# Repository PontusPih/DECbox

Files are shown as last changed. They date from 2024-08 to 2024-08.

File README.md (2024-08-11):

# DECbox
Blueprints and requirements for a box used to store DEC flipchips

## Examples

Overall dimensions for single, dual and quad cards:
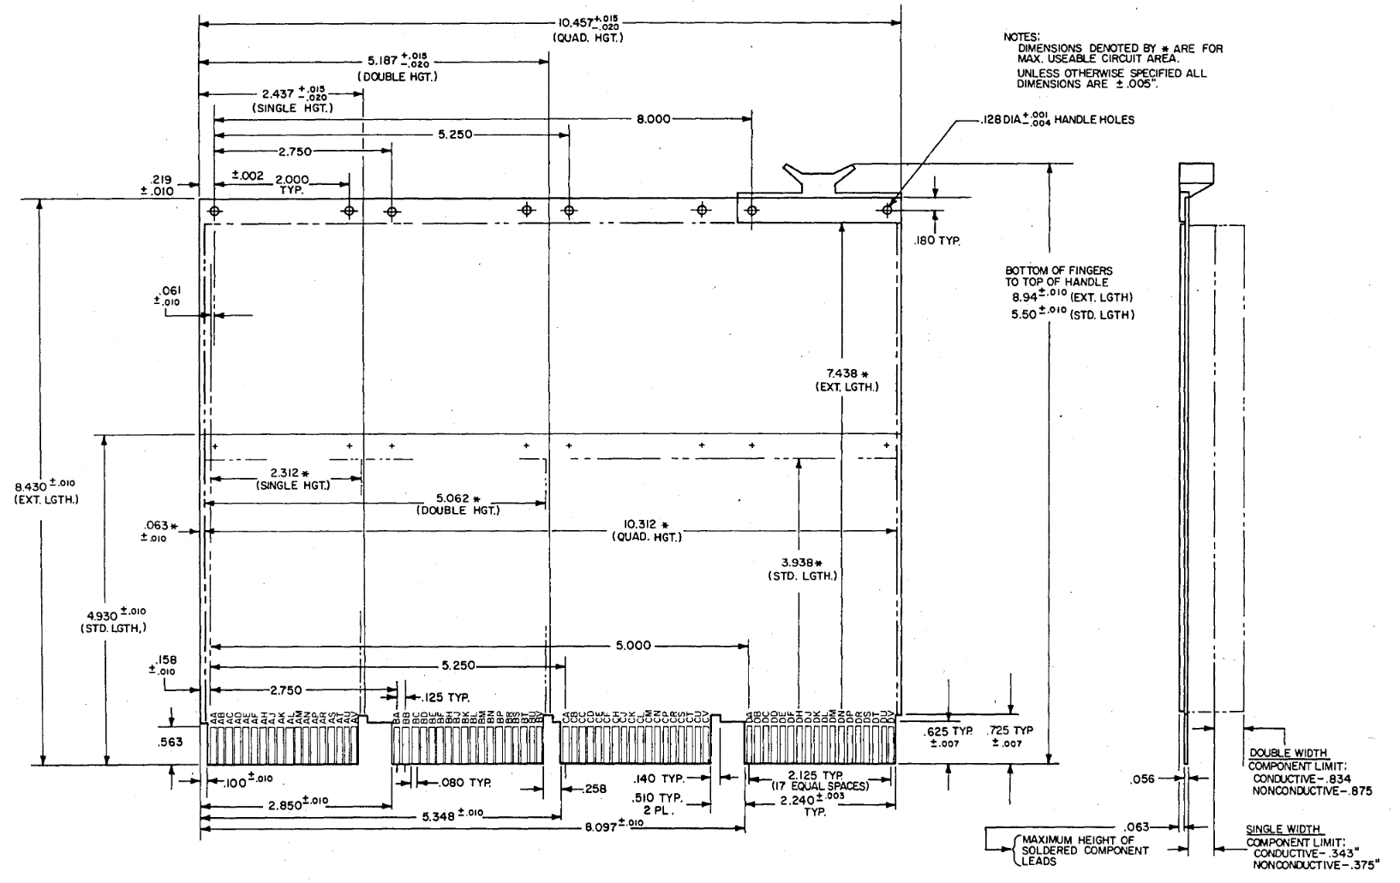
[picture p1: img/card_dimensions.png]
Card dimension


Overall dimesions for example Hex card (DH-11)

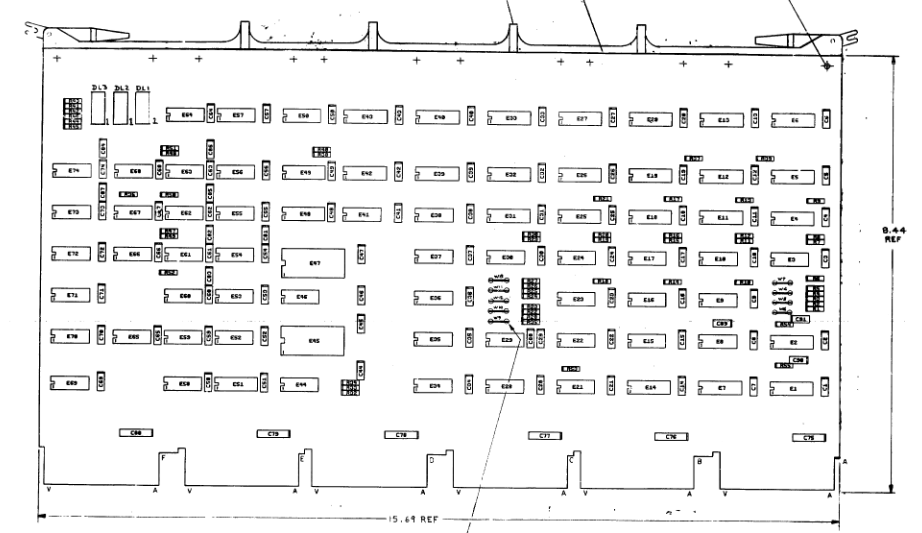
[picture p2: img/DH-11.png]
DH-11 drawing


Perspective views:

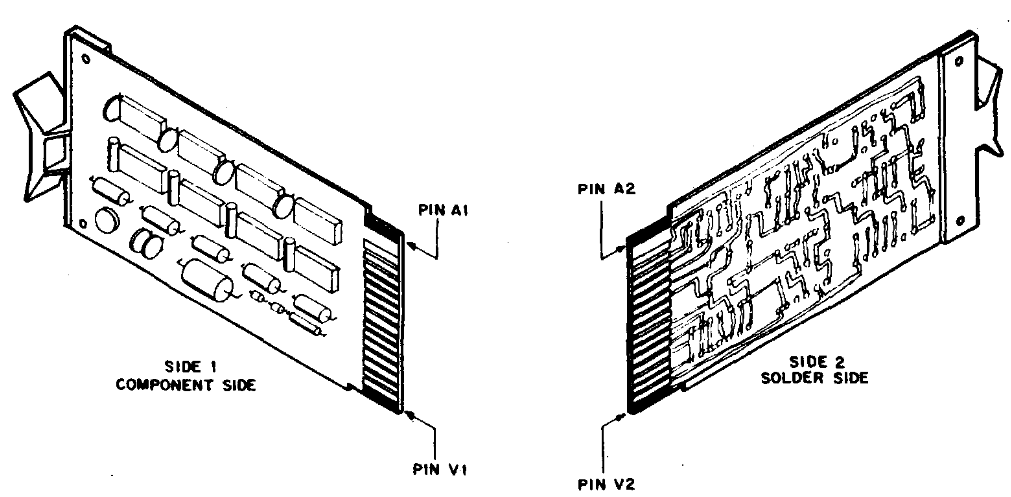
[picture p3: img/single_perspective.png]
Single card perspective


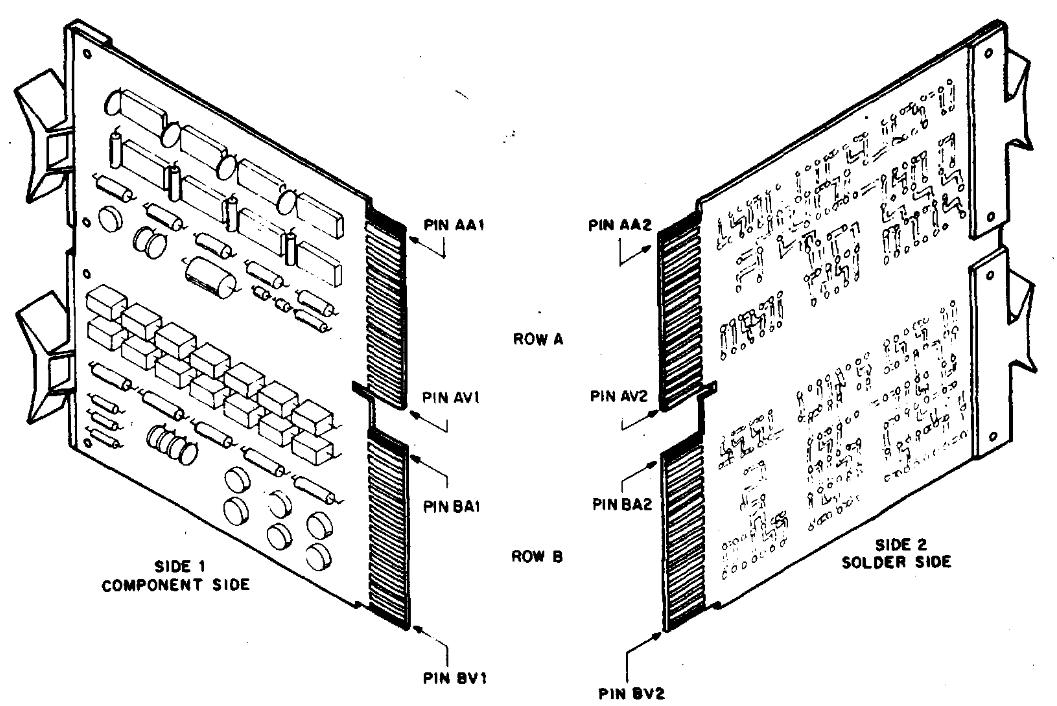
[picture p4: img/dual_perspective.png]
Dual card perspective


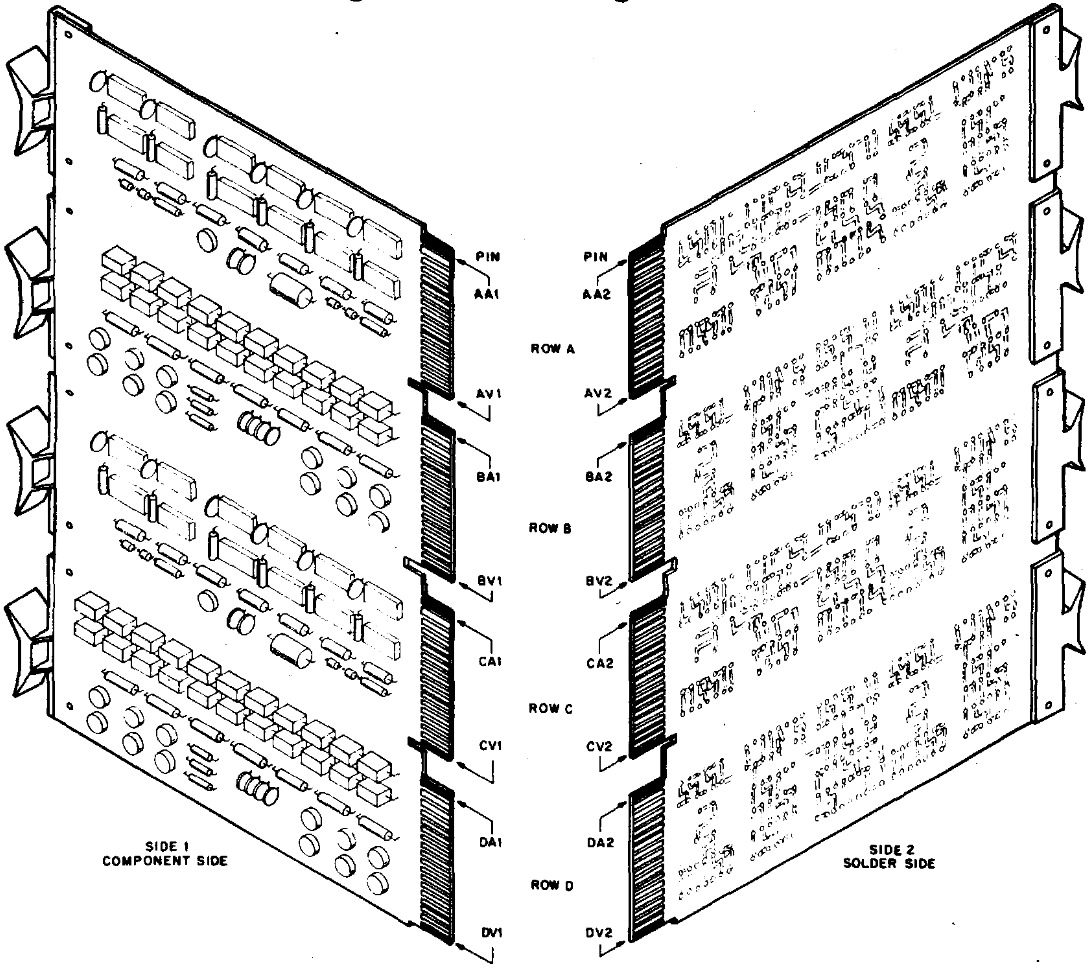
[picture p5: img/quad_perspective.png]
Quad card perspective


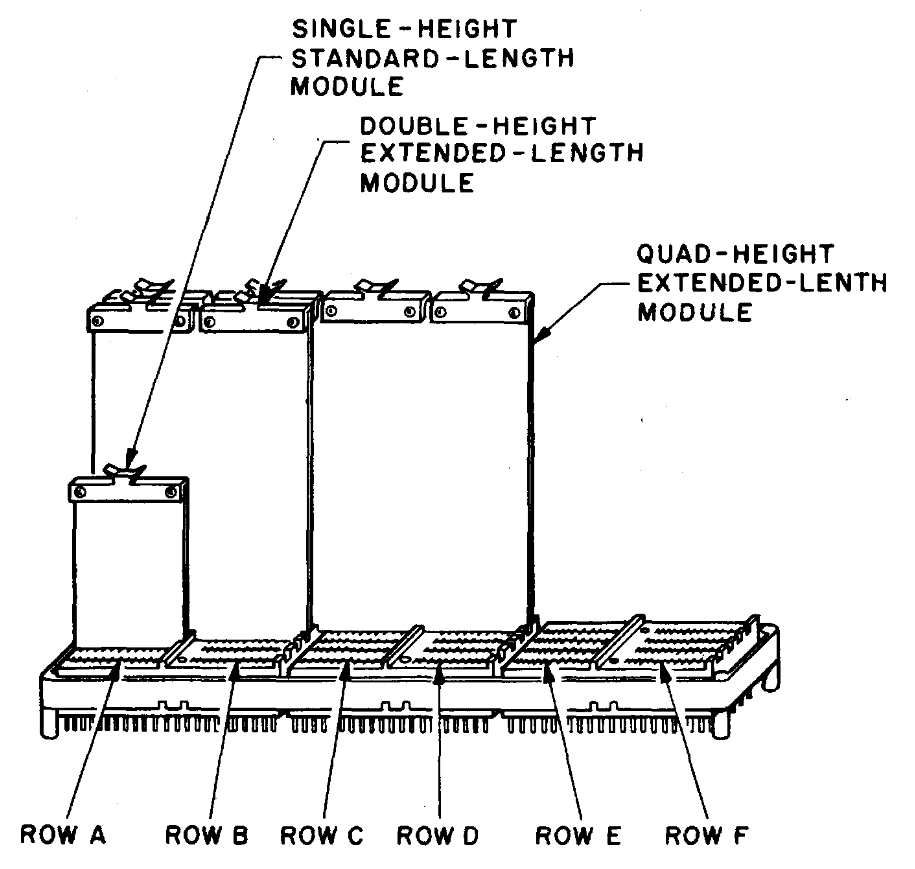
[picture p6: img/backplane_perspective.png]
Backplanve perspective


Example Quad card (DR-11):

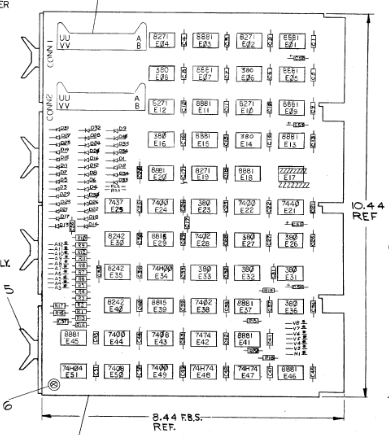
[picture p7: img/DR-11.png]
DR-11 drawing


## Hard requirements

The box must:
1. fit DEC Hex wide cards lengthwise
2. fit DEC Quad wide cards along the breadth
3. cover the full height of the cards with handles
4. support the cards along the edge connecter
5. handle the weight of a full box of either quad or hex cards without deforming
6. avoid contact with the components of the cards
7. avoid interference between cards
8. avoid binding between the box and cards
9. have tight enough tolerance to avoid rattling

## Soft requirements

The box may:
1. accept sandwiched cards (such as the UNIBUS M9202 backplane connector)
2. have receptacle for "claw" to fasten boards that have them
3. lid that mates with board top edge without putting undue pressure on them
4. be stackable
5. have handles
6. allow dividers that creates room for dual and single width cards
7. be easy to assemble from a "flat" packaging

## References

DR-11 Engineering drawings (has dimensions for QUAD card on page six): 

http://www.bitsavers.org/pdf/dec/unibus/DR11-C_EngrDrws.pdf

DH-11 Engineering drawings (has dimensions for HEX card on page seven): 

http://www.bitsavers.org/pdf/dec/unibus/DH11_EngrDrws_Jul76.pdf

Module dimensions and perspective drawings (pages 21-24)

http://www.bitsavers.org/pdf/dec/handbooks/Digital_Logic_Handbook_1975-76.pdf

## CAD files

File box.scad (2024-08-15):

// All dimensions in mm unless scaled to inch

// Hard dimensions

inch = 25.4;

hex_board_w = 15.69 * inch;
quad_board_w = 10.45 * inch;
dual_board_w = 5.19 * inch;
single_board_w = 2.44 * inch;
board_h = 8.44 * inch;
half_board_h = 4.94 * inch;
component_clearance = 0.063 * inch; // From edge of board to component area
component_h = 0.375 * inch; // From board surface to top of tallest compoent
solder_leads_clearance = 0.063 * inch;
board_thickness = 0.056 * inch;

// Soft dimensions

box_wall_w = 10;
handle_slot_w = 5;
handle_slot_h = 5;
first_slot_clearance = 10;
slot_width = 3;
slot_clearance = 0.25; // Extra wiggle room on each side of board
board_h_clearance = 2; // From tallest component to next board

steer_length = 30;      // instyrning av kortet

// calculated dimensions

slot_depth = component_clearance + slot_clearance;
box_inner_w = hex_board_w + 2*component_clearance - 2*slot_depth;
box_inner_d = quad_board_w + 2*component_clearance - 2*slot_depth;
quad_slot_w = box_inner_d + 2*slot_depth;
hex_slot_w = box_inner_w + 2*slot_depth;
box_wall_h = board_h;
board_unit = solder_leads_clearance + board_thickness + component_h + board_h_clearance;
number_of_hex_slots = floor((box_inner_d - first_slot_clearance - board_unit) / board_unit);
number_of_quad_slots = floor((box_inner_w - first_slot_clearance - board_unit) / board_unit);

// Functional layout

// Short sides
difference() {
    union() {
        translate([-box_wall_w, -10, 0])
            #cube([box_wall_w,box_inner_d+20,box_wall_h]);
        translate([box_inner_w, -10, 0])
            #cube([box_wall_w,box_inner_d+20, box_wall_h]);
    }
    hex_slots();
}
    

// Long sides
difference() {
    union() {
        translate([0, box_inner_d, 0])
            cube([box_inner_w, box_wall_w, box_wall_h]);
        translate([0, -box_wall_w, 0])
            cube([box_inner_w, box_wall_w, box_wall_h]);
    }
    quad_slots();
}


module quad_slots() {
    translate([first_slot_clearance, -slot_depth, -1]) {
        for(i = [0: number_of_quad_slots]) {
            translate([i * board_unit, 0, 0])
            union() {
                cube([slot_width, 2.5, box_wall_h + 2]);   //Pih
                     translate([first_slot_clearance+6, slot_depth+0.1, 186])
                    rotate([0,-90,90])
                        steer();
            }
       }
        
    }
}

module hex_slots() {
    translate([-slot_depth, first_slot_clearance, -1]) {
        for(i = [0: number_of_hex_slots]) {
            translate([0, i * board_unit, 0] )
                cube([hex_slot_w, slot_width, box_wall_h + 2]);
        }
    }
}

module steer() {
    linear_extrude(slot_depth+0.1)                              //+0.1 för att OS kräver det se rad 70
        polygon([[0,0],[steer_length,-4],[steer_length,4]]);    
}


    
    
    
    
    
    
    
    
    

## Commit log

2024-08-11 Add box drawing with initial dimensions
    [box.scad]
2024-08-11 Add correct measurements and create slots
    [box.scad]
2024-08-15 Lagt till steer (styrning).
    [box.scad]
